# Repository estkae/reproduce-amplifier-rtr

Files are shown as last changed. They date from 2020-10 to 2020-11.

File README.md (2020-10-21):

# Reproduce amplifier for reel to reel tape recorders

Mainly built for Soviet-era tape recorders using heads: 6В24.080 and similar. Main emphasis is made on accuracy of the reproduction, targeting both precise and noise free reproduction. For this reason it is using ultra low noise AD8429 instrumentation amplifiers and has very careful ground layout. 

It wasn't tested with other speeds than 19 cm/s speed.

Dedicated to my father Vladimir Sibiryakov.

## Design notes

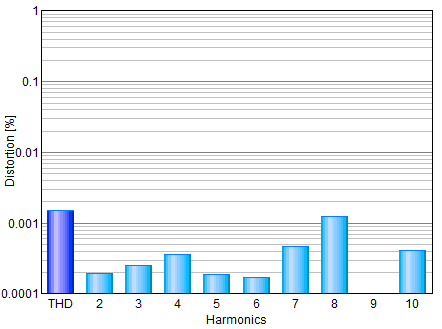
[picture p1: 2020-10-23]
images/1k-thd-harmonics.png

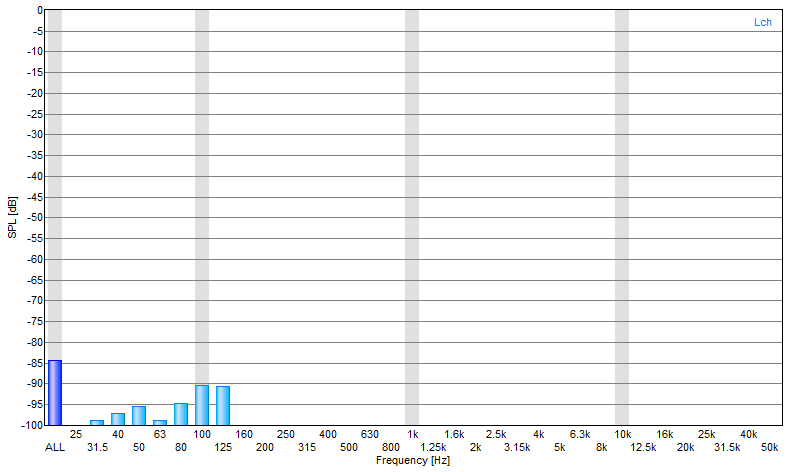
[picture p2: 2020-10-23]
images/noise-freq.png

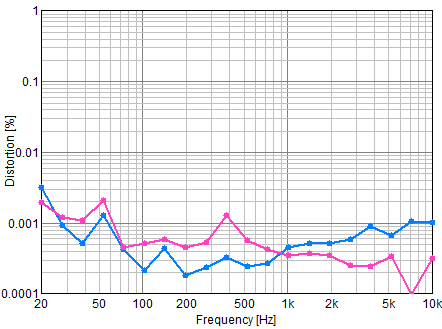
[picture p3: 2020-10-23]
images/thd-freq sweep.png

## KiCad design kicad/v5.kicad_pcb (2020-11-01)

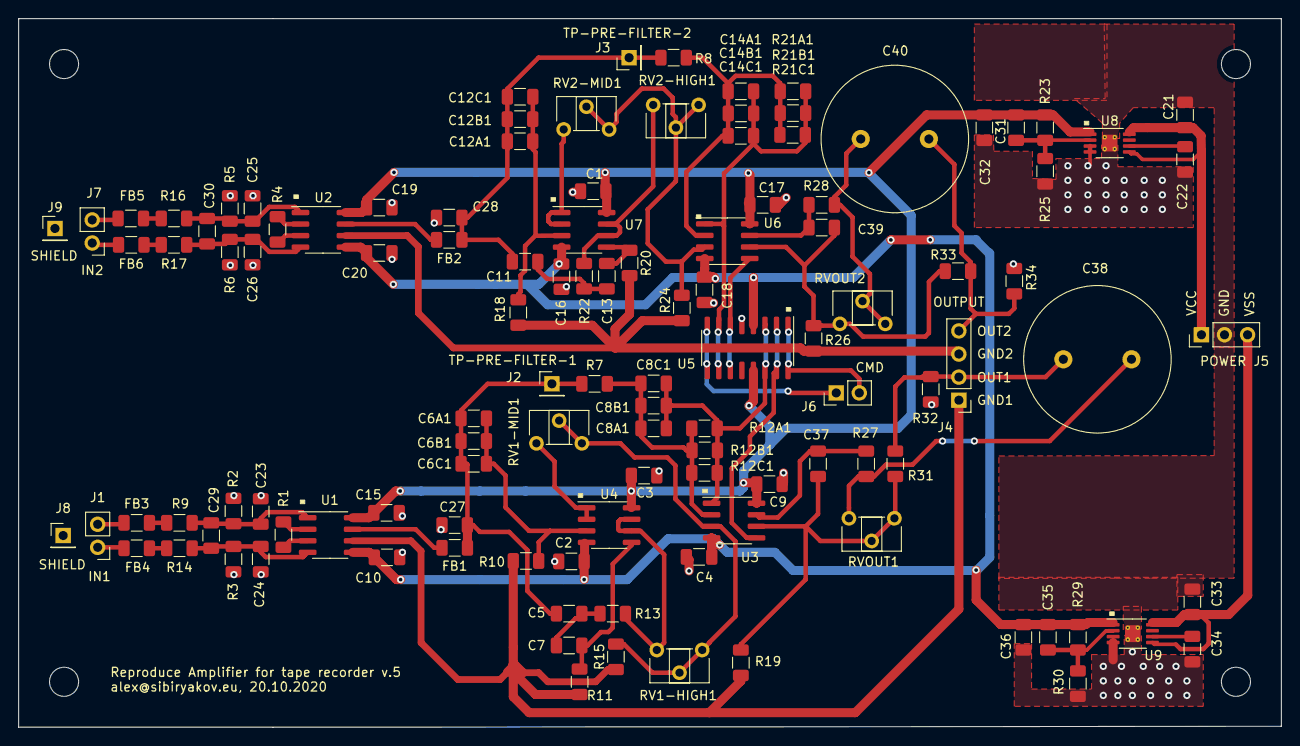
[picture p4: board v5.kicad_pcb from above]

Board: 2 copper layers, 139.0 x 78.0 mm, 116 parts (0 on the bottom side), 57 nets.

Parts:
C1, C2, C3, C4, C9, C10, C15, C16, C17, C18, C19, C20, C27, C28: 0.1uF; C_1206_3216Metric
C5, C7: 6.8n, 1%; C_1206_3216Metric
C6A1, C6B1, C8A1, C8B1, C12A1, C12B1, C14A1, C14B1: 39n, 1%; C_1206_3216Metric
C6C1, C12C1: 22n, 1%; C_1206_3216Metric
C8C1, C14C1: 82n, 1%; C_1206_3216Metric
C11, C13: 6.8n; C_1206_3216Metric
C21, C32, C33, C36: 10u; C_1206_3216Metric
C22, C31, C34, C35: 10n; C_1206_3216Metric
C23, C24, C25, C26: 47p; C_1206_3216Metric
C29, C30: 10nF; C_1206_3216Metric
C37, C39: 100pF; C_1206_3216Metric
C38, C40: 100U 35V NP; C_Radial_D16.0mm_H25.0mm_P7.50mm
FB1, FB2: Ferrite_Bead; L_1206_3216Metric
FB3, FB4, FB5, FB6: Ferrite_Bead_Small; L_1206_3216Metric
J1: IN1; PinHeader_1x02_P2.54mm_Vertical
J2: TP-PRE-FILTER-1; PinHeader_1x01_P2.54mm_Vertical
J3: TP-PRE-FILTER-2; PinHeader_1x01_P2.54mm_Vertical
J4: Output; PinHeader_1x04_P2.54mm_Vertical
J5: Power; PinHeader_1x03_P2.54mm_Vertical
J6: CMD; PinHeader_1x02_P2.54mm_Vertical
J7: IN2; PinHeader_1x02_P2.54mm_Vertical
J8: SHIELD1; PinHeader_1x01_P2.54mm_Vertical
J9: SHIELD2; PinHeader_1x01_P2.54mm_Vertical
R1, R4: 12.1; R_1206_3216Metric
R2, R3, R5, R6: 22k; R_1206_3216Metric
R7, R8: 5.6k; R_1206_3216Metric
R9, R14, R16, R17: 33; R_1206_3216Metric
R10: 1.5k, 1%; R_1206_3216Metric
R11, R20: 1.25k; R_1206_3216Metric
R12A1, R21A1: 18k, 1%; R_1206_3216Metric
R12B1, R21B1: 39k, 1%; R_1206_3216Metric
R12C1, R21C1: 51k, 1%; R_1206_3216Metric
R13, R22: 625; R_1206_3216Metric
R15, R24: 3.9k; R_1206_3216Metric
R18: 1.5k; R_1206_3216Metric
R19, R26: 560; R_1206_3216Metric
R23, R29: 91k; R_1206_3216Metric
R25, R30: 10k; R_1206_3216Metric
R27, R28: 68; R_1206_3216Metric
R31, R33: 1K; R_1206_3216Metric
R32, R34: 22K; R_1206_3216Metric
RV1-HIGH1, RV1-MID1, RV2-MID1: 3k; Potentiometer_Piher_PT-6-H_Horizontal
RV2-HIGH1: 3K; Potentiometer_Piher_PT-6-H_Horizontal
RVOUT1, RVOUT2: 7.5k; Potentiometer_Piher_PT-6-H_Horizontal
U1, U2: AD8429; SOIC-8_3.9x4.9mm_P1.27mm
U3, U4, U6, U7: NE5532; SOIC-8_3.9x4.9mm_P1.27mm
U5: ADG442; SOIC-16_3.9x9.9mm_P1.27mm
U8: TPS7A49; MSOP-8-1EP_3x3mm_P0.65mm_EP1.73x1.85mm_ThermalVias
U9: TPS7A30xx; MSOP-8-1EP_3x3mm_P0.65mm_EP1.73x1.85mm_ThermalVias

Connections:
GND: C1.2, C2.2, C3.2, C4.2, C9.1, C10.1, C15.1, C16.1, C17.1, C18.1, C19.1, C20.1, C21.2, C22.1, C23.2, C24.2, C25.2, C26.2, C27.2, C28.2, C32.1, C33.2, C34.1, C36.1, J4.1, J4.3, J5.2, J8.1, J9.1, R2.2, R3.2, R5.2, R6.2, R10.2, R11.2, R15.1, R18.2, R19.2, R20.2, R24.1, R25.1, R26.2, R30.1, R32.2, R34.2, U1.6, U2.6, U5.5, U8.3, U8.4, U8.9, U9.3, U9.4, U9.9
unnamed: C5.1, C7.2, R13.2
unnamed: C6A1.1, C6B1.1, C6C1.1, R10.1, U4.3
unnamed: C7.1, R11.1, U4.5
unnamed: C8A1.1, C8B1.1, C8C1.1, R12A1.1, R12B1.1, R12C1.1, U3.1, U5.3, U5.14
unnamed: C8A1.2, C8B1.2, C8C1.2, R7.1, R12A1.2, R12B1.2, R12C1.2, U3.2
unnamed: C11.1, C13.2, R22.2
unnamed: C11.2, C12A1.2, C12B1.2, C12C1.2, C28.1, FB2.1, J3.1, R8.2
unnamed: C12A1.1, C12B1.1, C12C1.1, R18.1, U7.3
unnamed: C13.1, R20.1, U7.5
unnamed: C14A1.1, C14B1.1, C14C1.1, R21A1.1, R21B1.1, R21C1.1, U5.7, U5.10, U6.1
unnamed: C14A1.2, C14B1.2, C14C1.2, R8.1, R21A1.2, R21B1.2, R21C1.2, U6.2
unnamed: C21.1, J5.1, U8.5, U8.8
unnamed: C22.2, U8.6
unnamed: C23.1, C29.1, R2.1, R9.1, U1.1
unnamed: C24.1, C29.2, R3.1, R14.1, U1.4
unnamed: C25.1, C30.1, R5.1, R16.1, U2.1
unnamed: C26.1, C30.2, R6.1, R17.1, U2.4
unnamed: C5.2, C6A1.2, C6B1.2, C6C1.2, C27.1, FB1.1, J2.1, R7.2
unnamed: C31.1, R23.1, R25.2, U8.2
unnamed: C33.1, J5.3, U9.5, U9.8
unnamed: C34.2, U9.6
unnamed: C35.1, R29.1, R30.2, U9.2
unnamed: C37.1, R27.2, U3.7
unnamed: C37.2, R19.1, R31.2, RVOUT1.1, RVOUT1.2, U3.6
unnamed: C38.1, J4.2, R31.1, R32.1
unnamed: C38.2, R27.1, RVOUT1.3
unnamed: C39.1, R28.1, U6.7
unnamed: C39.2, R26.1, R33.2, RVOUT2.1, U6.6
unnamed: C40.1, J4.4, R33.1, R34.1
unnamed: C40.2, R28.2, RVOUT2.2, RVOUT2.3
unnamed: FB1.2, U1.7
unnamed: FB2.2, U2.7
unnamed: FB3.1, R9.2
unnamed: FB3.2, J1.2
unnamed: FB4.1, R14.2
unnamed: FB4.2, J1.1
unnamed: FB5.1, R16.2
unnamed: FB5.2, J7.2
unnamed: FB6.1, R17.2
unnamed: FB6.2, J7.1
unnamed: J6.1, U5.8, U5.9
unnamed: J6.2, U5.1, U5.16
unnamed: R1.1, U1.2
unnamed: R1.2, U1.3
unnamed: R4.1, U2.2
unnamed: R4.2, U2.3
unnamed: R13.1, RV1-HIGH1.3, U4.6, U4.7
unnamed: R15.2, RV1-HIGH1.1, RV1-HIGH1.2, RV1-MID1.2, RV1-MID1.3, U3.3
unnamed: R22.1, RV2-HIGH1.3, U7.6, U7.7
unnamed: R24.2, RV2-HIGH1.1, RV2-HIGH1.2, RV2-MID1.2, RV2-MID1.3, U6.3
unnamed: RV1-MID1.1, U4.1, U4.2
unnamed: RV2-MID1.1, U7.1, U7.2
unnamed: U3.5, U5.2, U5.15
unnamed: U5.6, U5.11, U6.5
VCC: C1.1, C3.1, C9.2, C15.2, C17.2, C19.2, C31.2, C32.2, R23.2, U1.8, U2.8, U3.8, U4.8, U5.13, U6.8, U7.8, U8.1
VSS: C2.1, C4.1, C10.2, C16.2, C18.2, C20.2, C35.2, C36.2, R29.2, U1.5, U2.5, U3.4, U4.4, U5.4, U6.4, U7.4, U9.1

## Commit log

2020-10-21 kicad and ltspice files
    [v5.kicad_pcb, v5.sch]
2020-10-21 Output stage PCB work
    [v5.kicad_pcb, v5.sch]
2020-10-21 WIP Capacitors from E12, and resistors from E24/12
    [v5.sch]
2020-10-25 E24 canges on PCB
    [v5.kicad_pcb, v5.sch]
2020-11-01 More work on putting filter capacitors, Proper net assignment on power regulators grounds
    [v5.kicad_pcb]
